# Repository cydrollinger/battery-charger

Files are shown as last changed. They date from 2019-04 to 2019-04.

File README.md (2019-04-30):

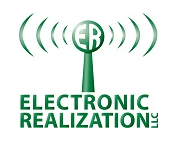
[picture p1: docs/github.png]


>Electronic Realization L.L.C.								   
>Design: Battery charger 4 Li cells		   
>Engineer: Cy Drollinger								   
>Date: 5/18												           
>Email: cy@elec-real.com	
>Website: https://elec-real.com							   
>Address: 2023 Stadium Dr Suite 2B #210 Bozeman, MT 59715				   
>Phone: 406-539-8117	

**NOTE:**
 This design has been tested and functions as specified. The design is provided gratis, so, please 
 think critically while utilizing and or redesigning. Open electronic circuitry can be dangerous due 
 to easily shorting circuits which can generate immediate and intense heat resulting in fire. Conversation is
 welcome to improve this design and repository, but, be advised ER is a professional design house and
 monetary compensation is required for additional work toward this design enabling your success.			   
	 
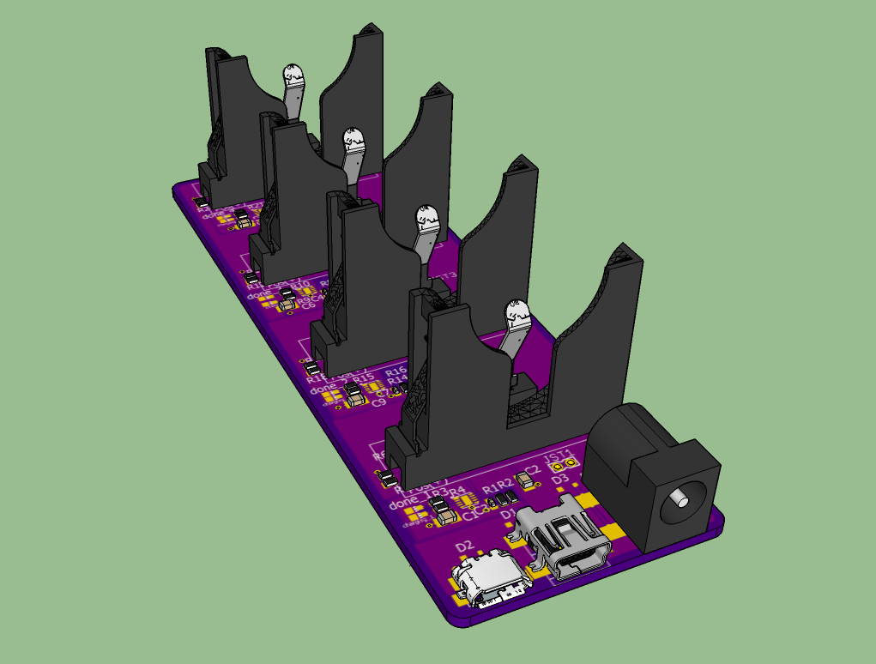
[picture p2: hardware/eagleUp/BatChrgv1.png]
Battery_charger


**PURPOSE:**
This is a hardware design that is capable of charging 4 Li ion cells. The design employs four different circuits
and charge currents: 100mA, 200mA, 400mA, and 800mA. The design files were created with Eagle Cadsoft v7.7 as a 
two layer board. Free Eagle version would be capable of viewing, and editing these files for redesign. 

>**File Arcitecture with a terse description**

* FOLDERS:
	* docs		: datasheets charging IC and battery holder
	* hardware	: eagle cadsoft(v7.7) hardware design files 	
		* eagleup		: 3D files 
		* library		: eagle part files 
		* manufacturing	: files required to produce the design
			* bom	: files created to order the parts
					* batteryCharger.txt	: 
					* batteryv1.1.csv	: digikey order
					* hundredUnits.txt	
			* gerber	: files generated to manufacture the board
			* 
	* readme.md	: this file

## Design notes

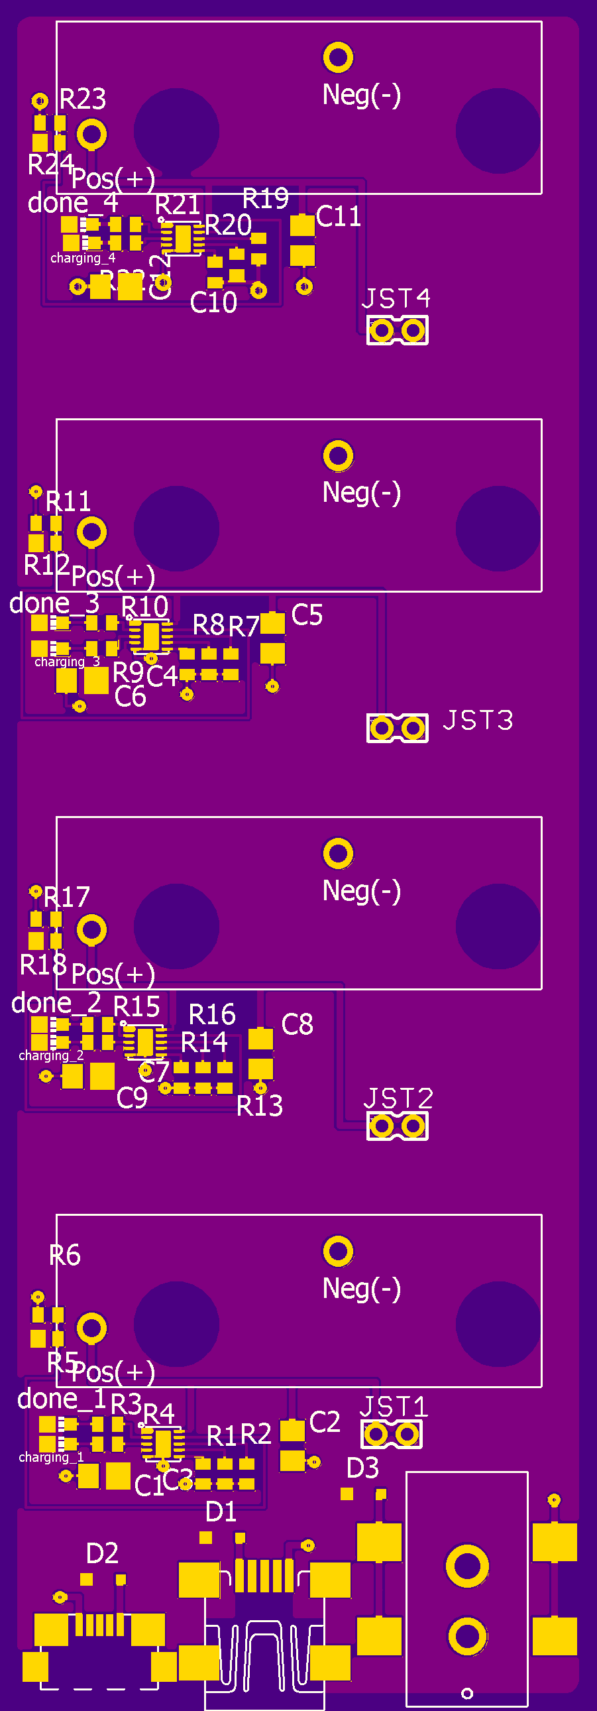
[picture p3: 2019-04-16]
hardware/eagleUp/eagleUp_batteryCharger_board_top.png

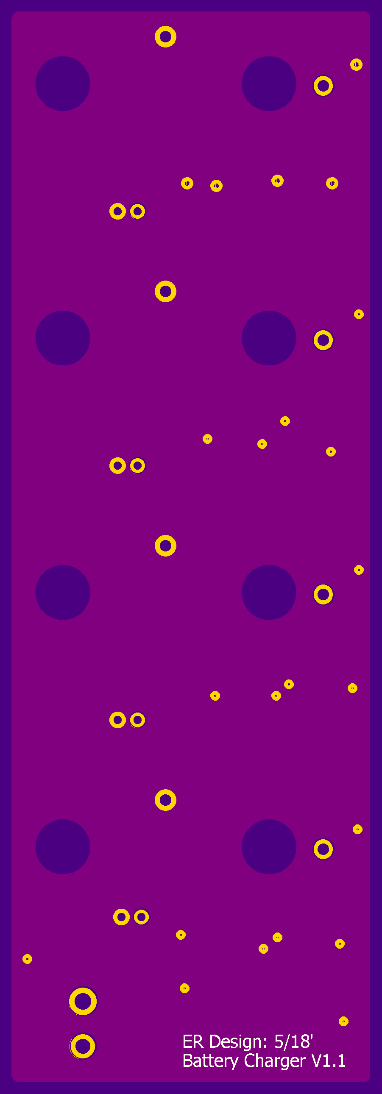
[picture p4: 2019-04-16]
hardware/eagleUp/eagleUp_batteryCharger_board_bottom.png

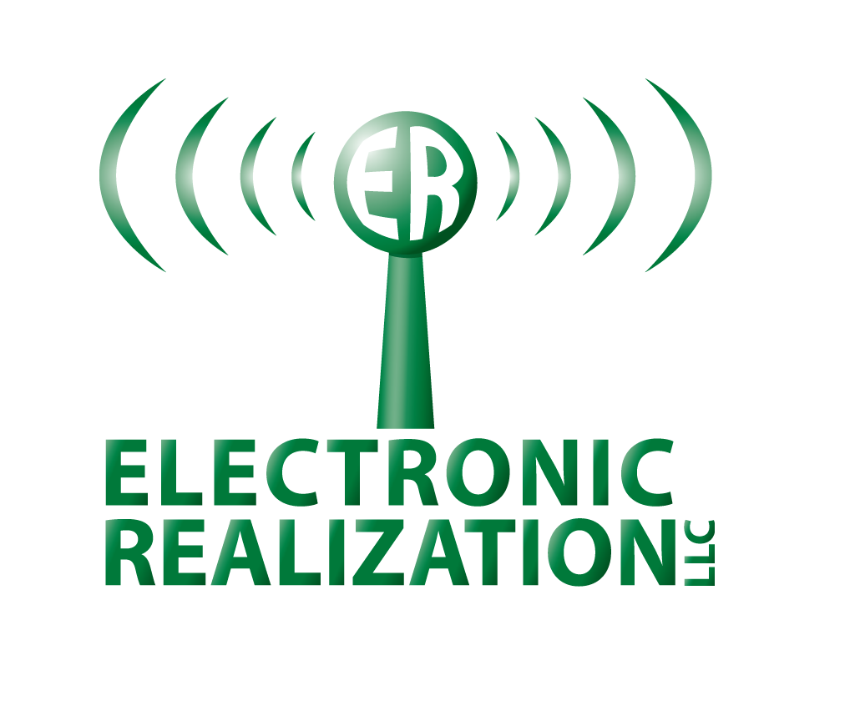
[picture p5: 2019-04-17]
docs/gihu.png

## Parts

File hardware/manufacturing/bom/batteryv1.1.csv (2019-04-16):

Index | Quantity | Part Number | Description | Customer Reference | Available Quantity | Backorder Quantity | Unit Price USD | Extended Price USD
1 | 3 | CP-002AHPJCT-ND | CONN PWR JACK 2X5.5MM SOLDER |  | 3 | 0 | 1.44 | 4.32
2 | 12 | 36-1068-ND | HOLDER BATTERY COIN 24.5MM VERT | BATTERYCHARGER: HOLDER | 12 | 0 | 1.642 | 19.7
3 | 3 | H2961CT-ND | CONN RECEPT MINI USB2.0 5POS | BATTERYCHARGER: MINIUSB | 3 | 0 | 0.99 | 2.97
4 | 12 | 455-1704-ND | CONN HEADER PH TOP 2POS 2MM |  | 12 | 0 | 0.162 | 1.94
5 | 25 | 160-1446-1-ND | LED GREEN CLEAR 0603 SMD | BATTERYV1.1: LED1-8 | 25 | 0 | 0.1556 | 3.89
6 | 3 | 863-1512-1-ND | 1.6A LINEAR LI-ION CHGR 10TDFN | BATTERYV1.1 | 3 | 0 | 0.94 | 2.82
7 | 100 | RHM1.5KCECT-ND | RES SMD 1.5K OHM 5% 1/16W 0402 | BATTERYV1.1: R3,R4,R9,R15,R16,R21,R22 | 100 | 0 | 0.0057 | 0.57
8 | 10 | RHM16.5KCHCT-ND | RES SMD 16.5K OHM 1% 1/8W 0805 | BATTERYV1.1: R1 | 10 | 0 | 0.021 | 0.21
9 | 20 | RHM10KDCT-ND | RES SMD 10K OHM 5% 1/4W 0603 | BATTERYV1.1: R5,R12,R18,R24, | 20 | 0 | 0.087 | 1.74
10 | 10 | RHM8.06KCDCT-ND | RES SMD 8.06K OHM 1% 1/16W 0402 | BATTERYV1.1: R8 | 10 | 0 | 0.014 | 0.14
11 | 10 | P4.02KLCT-ND | RES SMD 4.02K OHM 1% 1/10W 0402 | BATTERYV1.1: R14 | 10 | 0 | 0.043 | 0.43
12 | 10 | YAG3048CT-ND | RES SMD 1.87K OHM 1% 1/16W 0402 | BATTERYV1.1: R20 | 10 | 0 | 0.013 | 0.13
13 | 10 | 445-2550-1-ND | SENSOR NTC 10K OHM 3380K 0402 | BATTERYV1.1: R6,R11,R17,R23 | 10 | 0 | 0.088 | 0.88
14 | 25 | 490-10693-1-ND | CAP CER 10UF 4V X5R 0402 |  | 25 | 0 | 0.18 | 4.5
15 | 20 | 490-6287-1-ND | CAP CER 0.1UF 6.3V X5R 0402 | BATTERYV1.1: C3,C4,C7.C10 | 20 | 0 | 0.035 | 0.7

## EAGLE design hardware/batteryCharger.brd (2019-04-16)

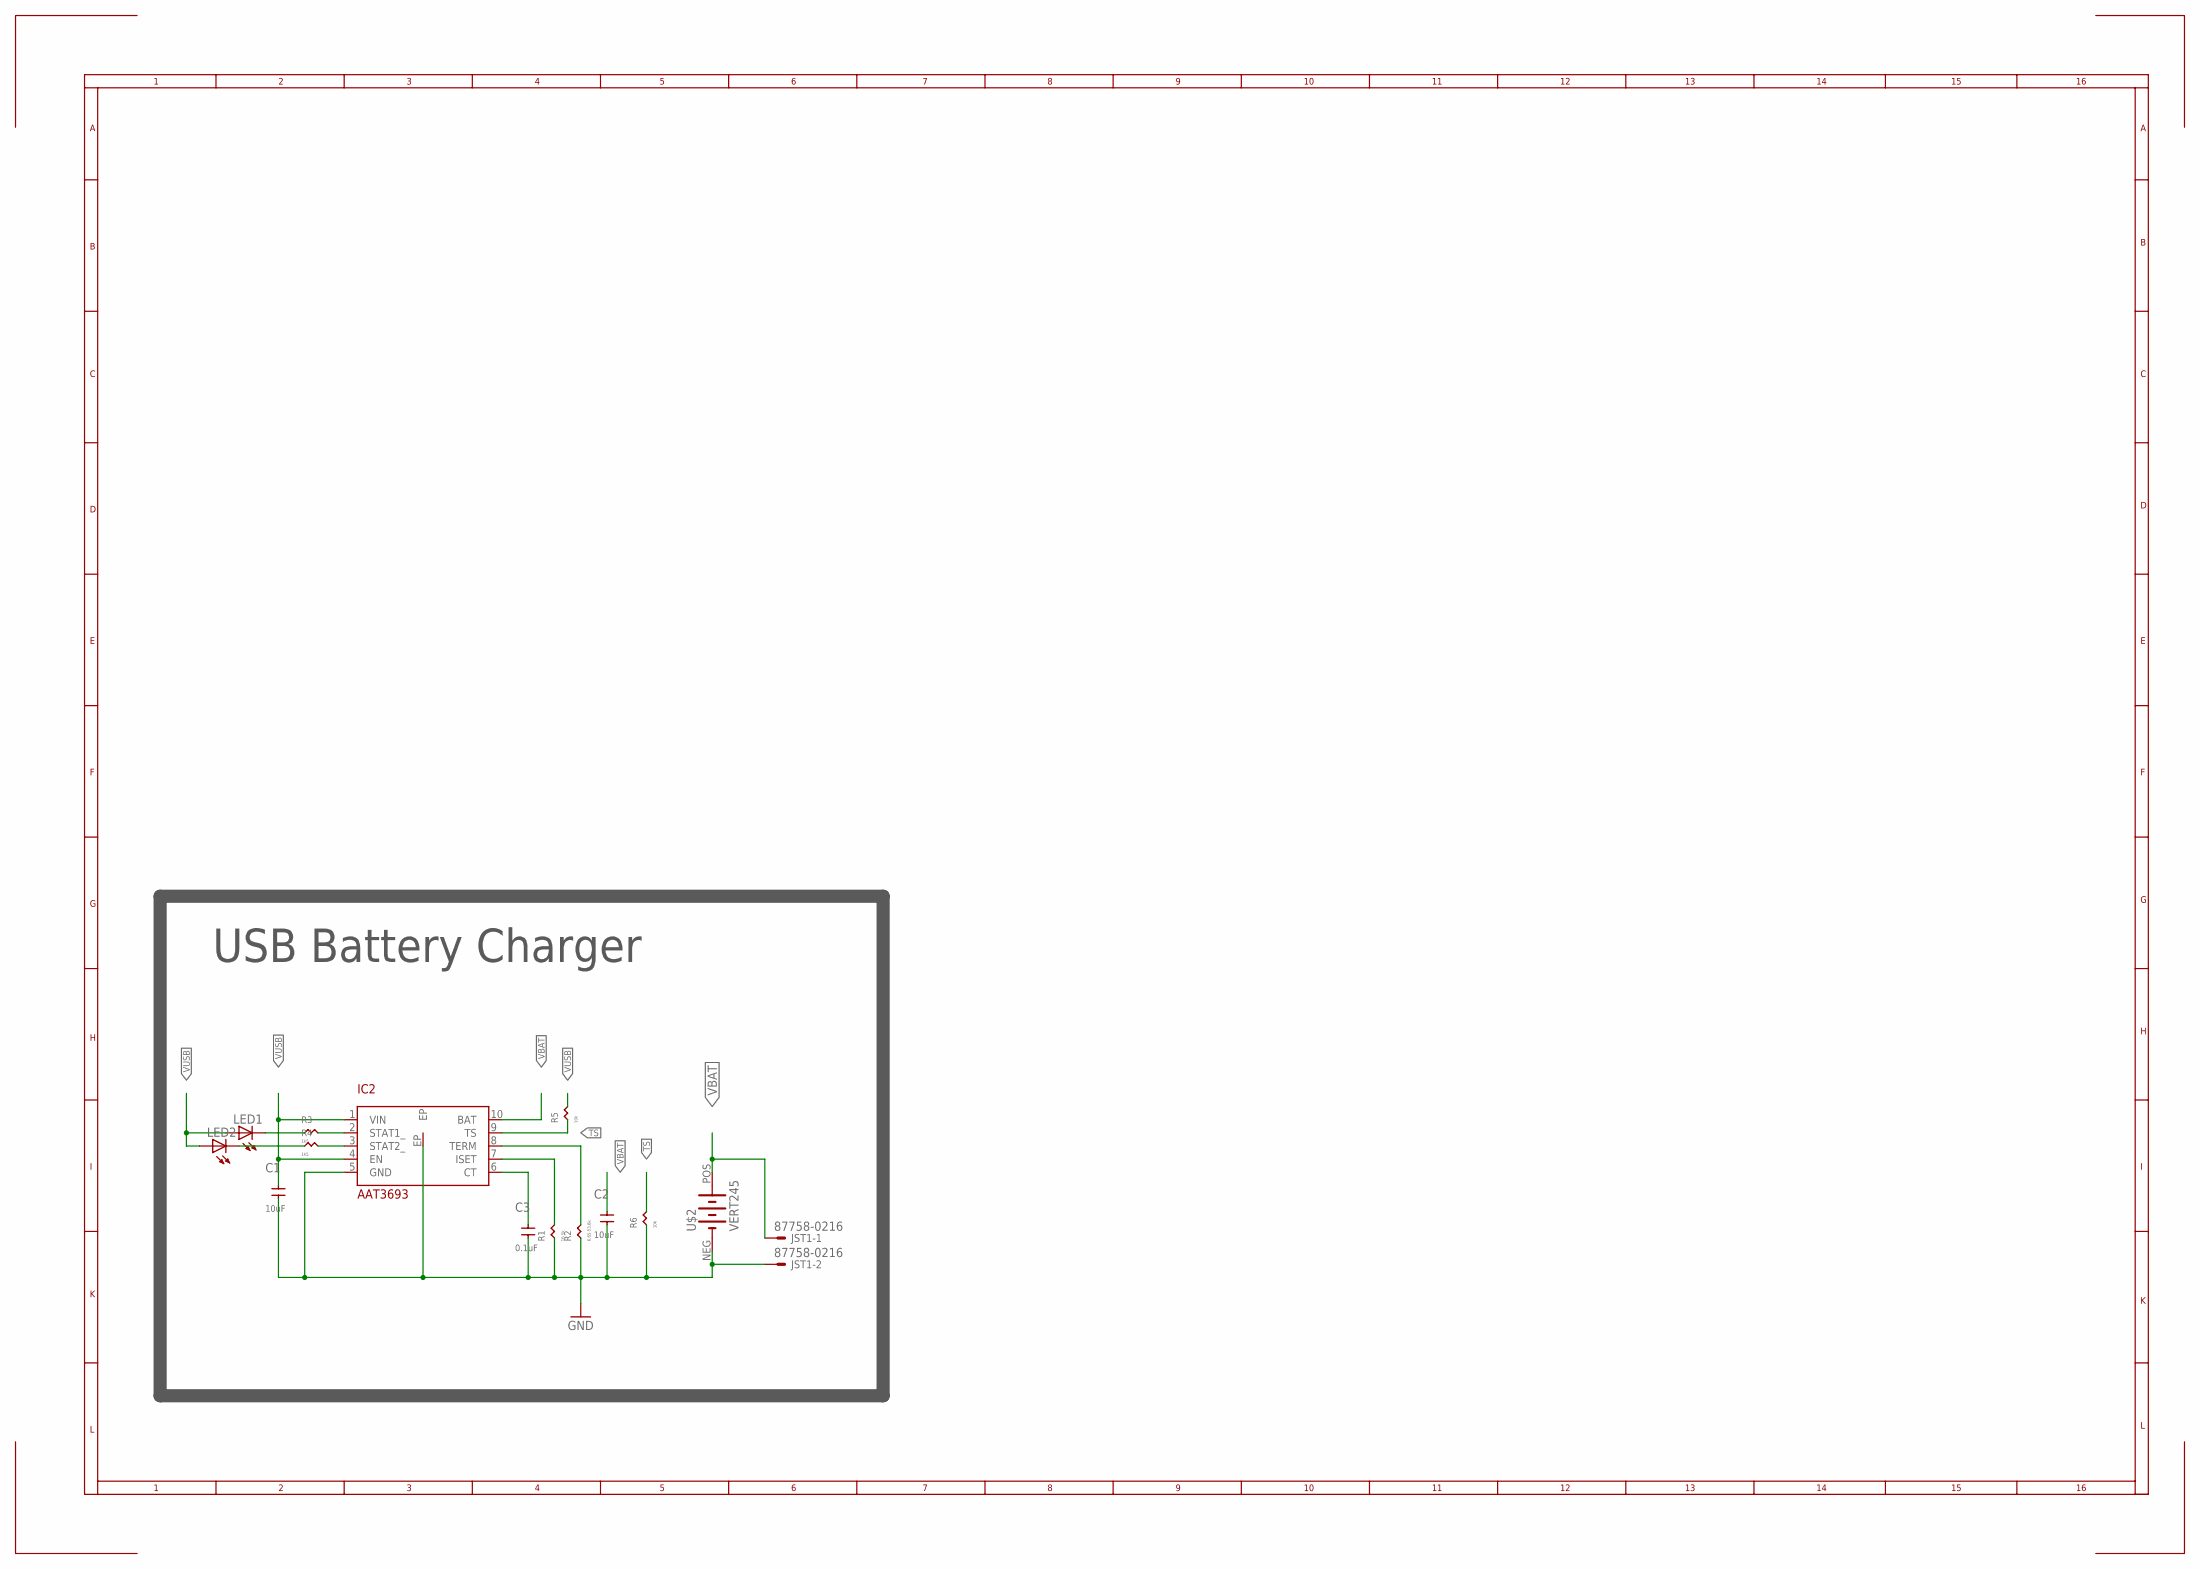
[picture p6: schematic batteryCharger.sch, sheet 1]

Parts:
C1, C2: 10uF; C0805
C3: 0.1uF; C0402
IC2: AAT3693
JST1: 87758-0216
LED1, LED2: LEDCHIP-LED0603; CHIP-LED0603
R1: 16.5k; R0402
R2: 6.65-53.6k; R0402
R3, R4: 1k5; R0402
R5, R6: 10k; R0402
U$2: VERT245

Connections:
GND: C1.1, C2.1, C3.1, IC2.5 (GND), IC2.EP, JST1.2, R1.1, R2.1, R6.1, U$2.NEG (-); also elsewhere on the board
unnamed: C3.2, IC2.6 (CT)
unnamed: IC2.7 (ISET), R1.2
unnamed: IC2.8 (TERM), R2.2
unnamed: IC2.3 (STAT2_), R4.2
unnamed: IC2.2 (STAT1_), R3.2
unnamed: LED1.C, R3.1
unnamed: LED2.C, R4.1
TS: IC2.9 (TS), R5.1, R6.2
VBAT: C2.2, IC2.10 (BAT), JST1.1, U$2.POS (+)
VUSB: C1.2, IC2.1 (VIN), IC2.4 (EN), LED1.A, LED2.A, R5.2; also elsewhere on the board

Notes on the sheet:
USB Battery Charger

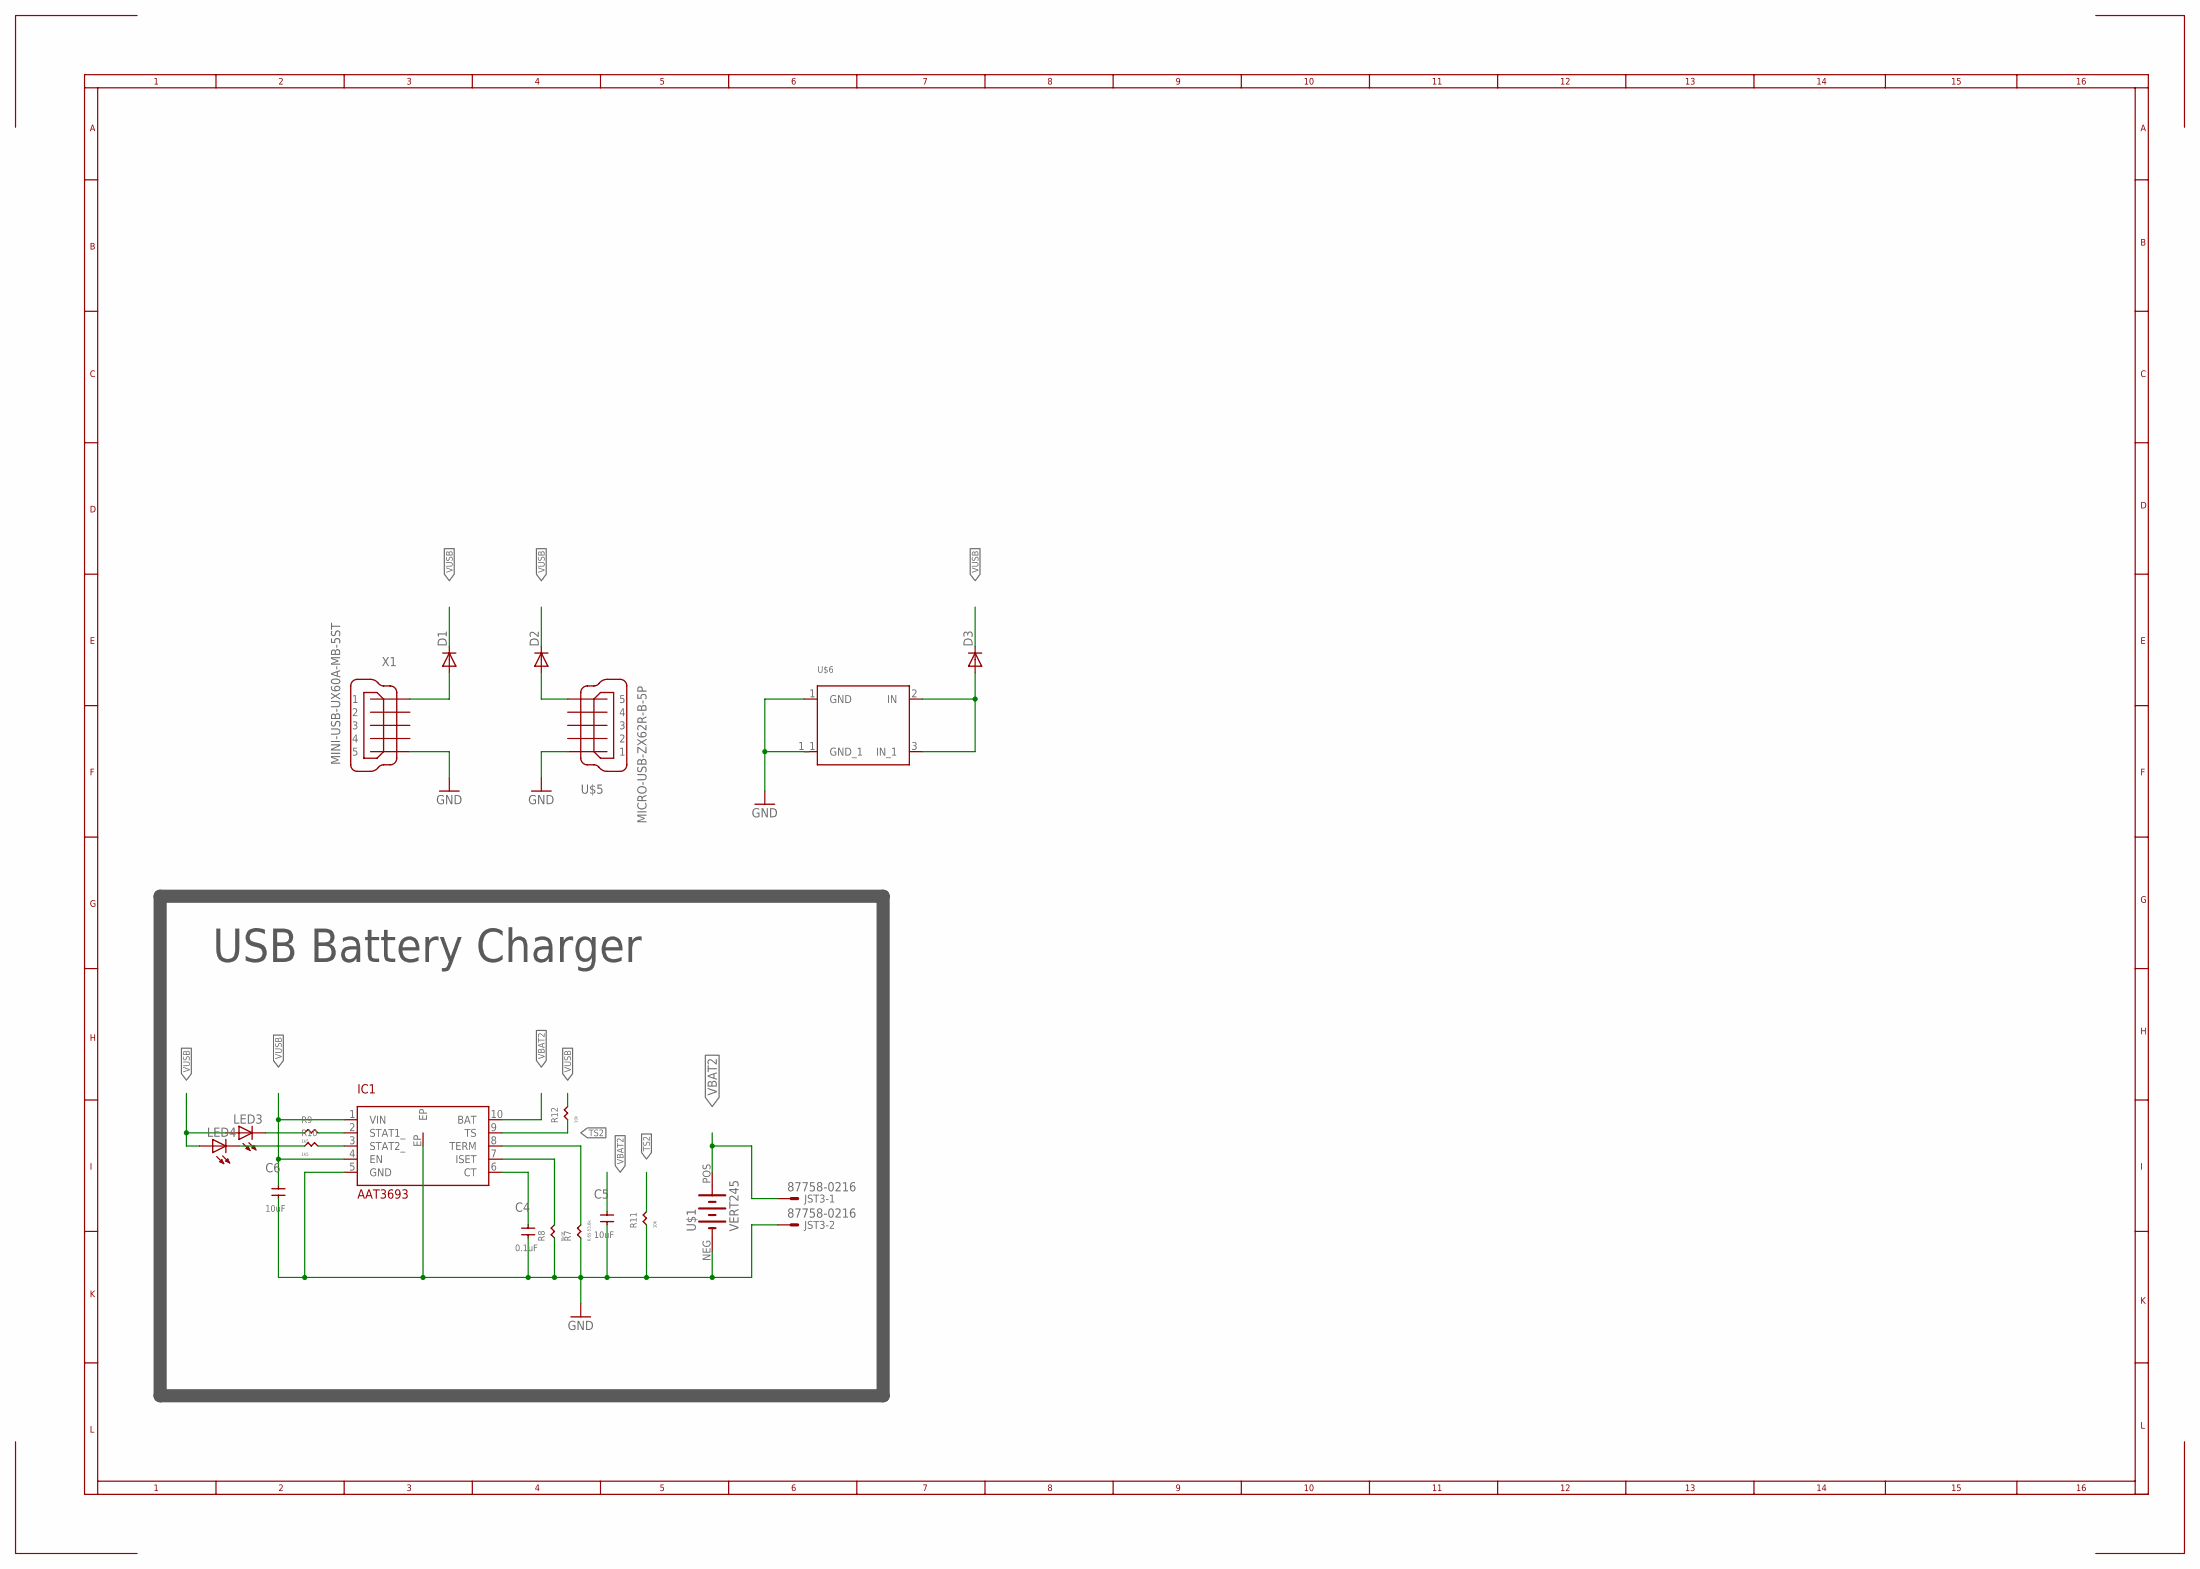
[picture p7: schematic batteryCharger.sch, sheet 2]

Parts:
C4: 0.1uF; C0402
C5, C6: 10uF; C0805
D1, D2, D3: DIODE-SOD323-R; SOD323-R; DIGIKEY BAT60AE6327HTSA1CT-ND
IC1: AAT3693
JST3: 87758-0216
LED3, LED4: LEDCHIP-LED0603; CHIP-LED0603
R7: 6.65-53.6k; R0402
R8: 8k06; R0402
R9, R10: 1k5; R0402
R11, R12: 10k; R0402
U$1: VERT245
U$5: MICRO-USB-ZX62R-B-5P; ZX62R-B-5P
U$6: PJ-002A_SMT
X1: MINI-USB-UX60A-MB-5ST; UX60A-MB-5ST

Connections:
GND: C4.1, C5.1, C6.1, IC1.5 (GND), IC1.EP, JST3.2, R7.1, R8.1, R11.1, U$1.NEG (-), U$5.1, U$6.1 (GND), U$6.1_1 (GND_1), X1.5; also elsewhere on the board
unnamed: C4.2, IC1.6 (CT)
unnamed: IC1.7 (ISET), R8.2
unnamed: IC1.8 (TERM), R7.2
unnamed: IC1.3 (STAT2_), R10.2
unnamed: IC1.2 (STAT1_), R9.2
unnamed: LED3.C, R9.1
unnamed: LED4.C, R10.1
unnamed: D1.A, X1.1
unnamed: D2.A, U$5.5
unnamed: D3.A, U$6.2 (IN), U$6.3 (IN_1)
TS2: IC1.9 (TS), R11.2, R12.1
VBAT2: C5.2, IC1.10 (BAT), JST3.1, U$1.POS (+)
VUSB: C6.2, D1.C, D2.C, D3.C, IC1.1 (VIN), IC1.4 (EN), LED3.A, LED4.A, R12.2; also elsewhere on the board

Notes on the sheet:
USB Battery Charger

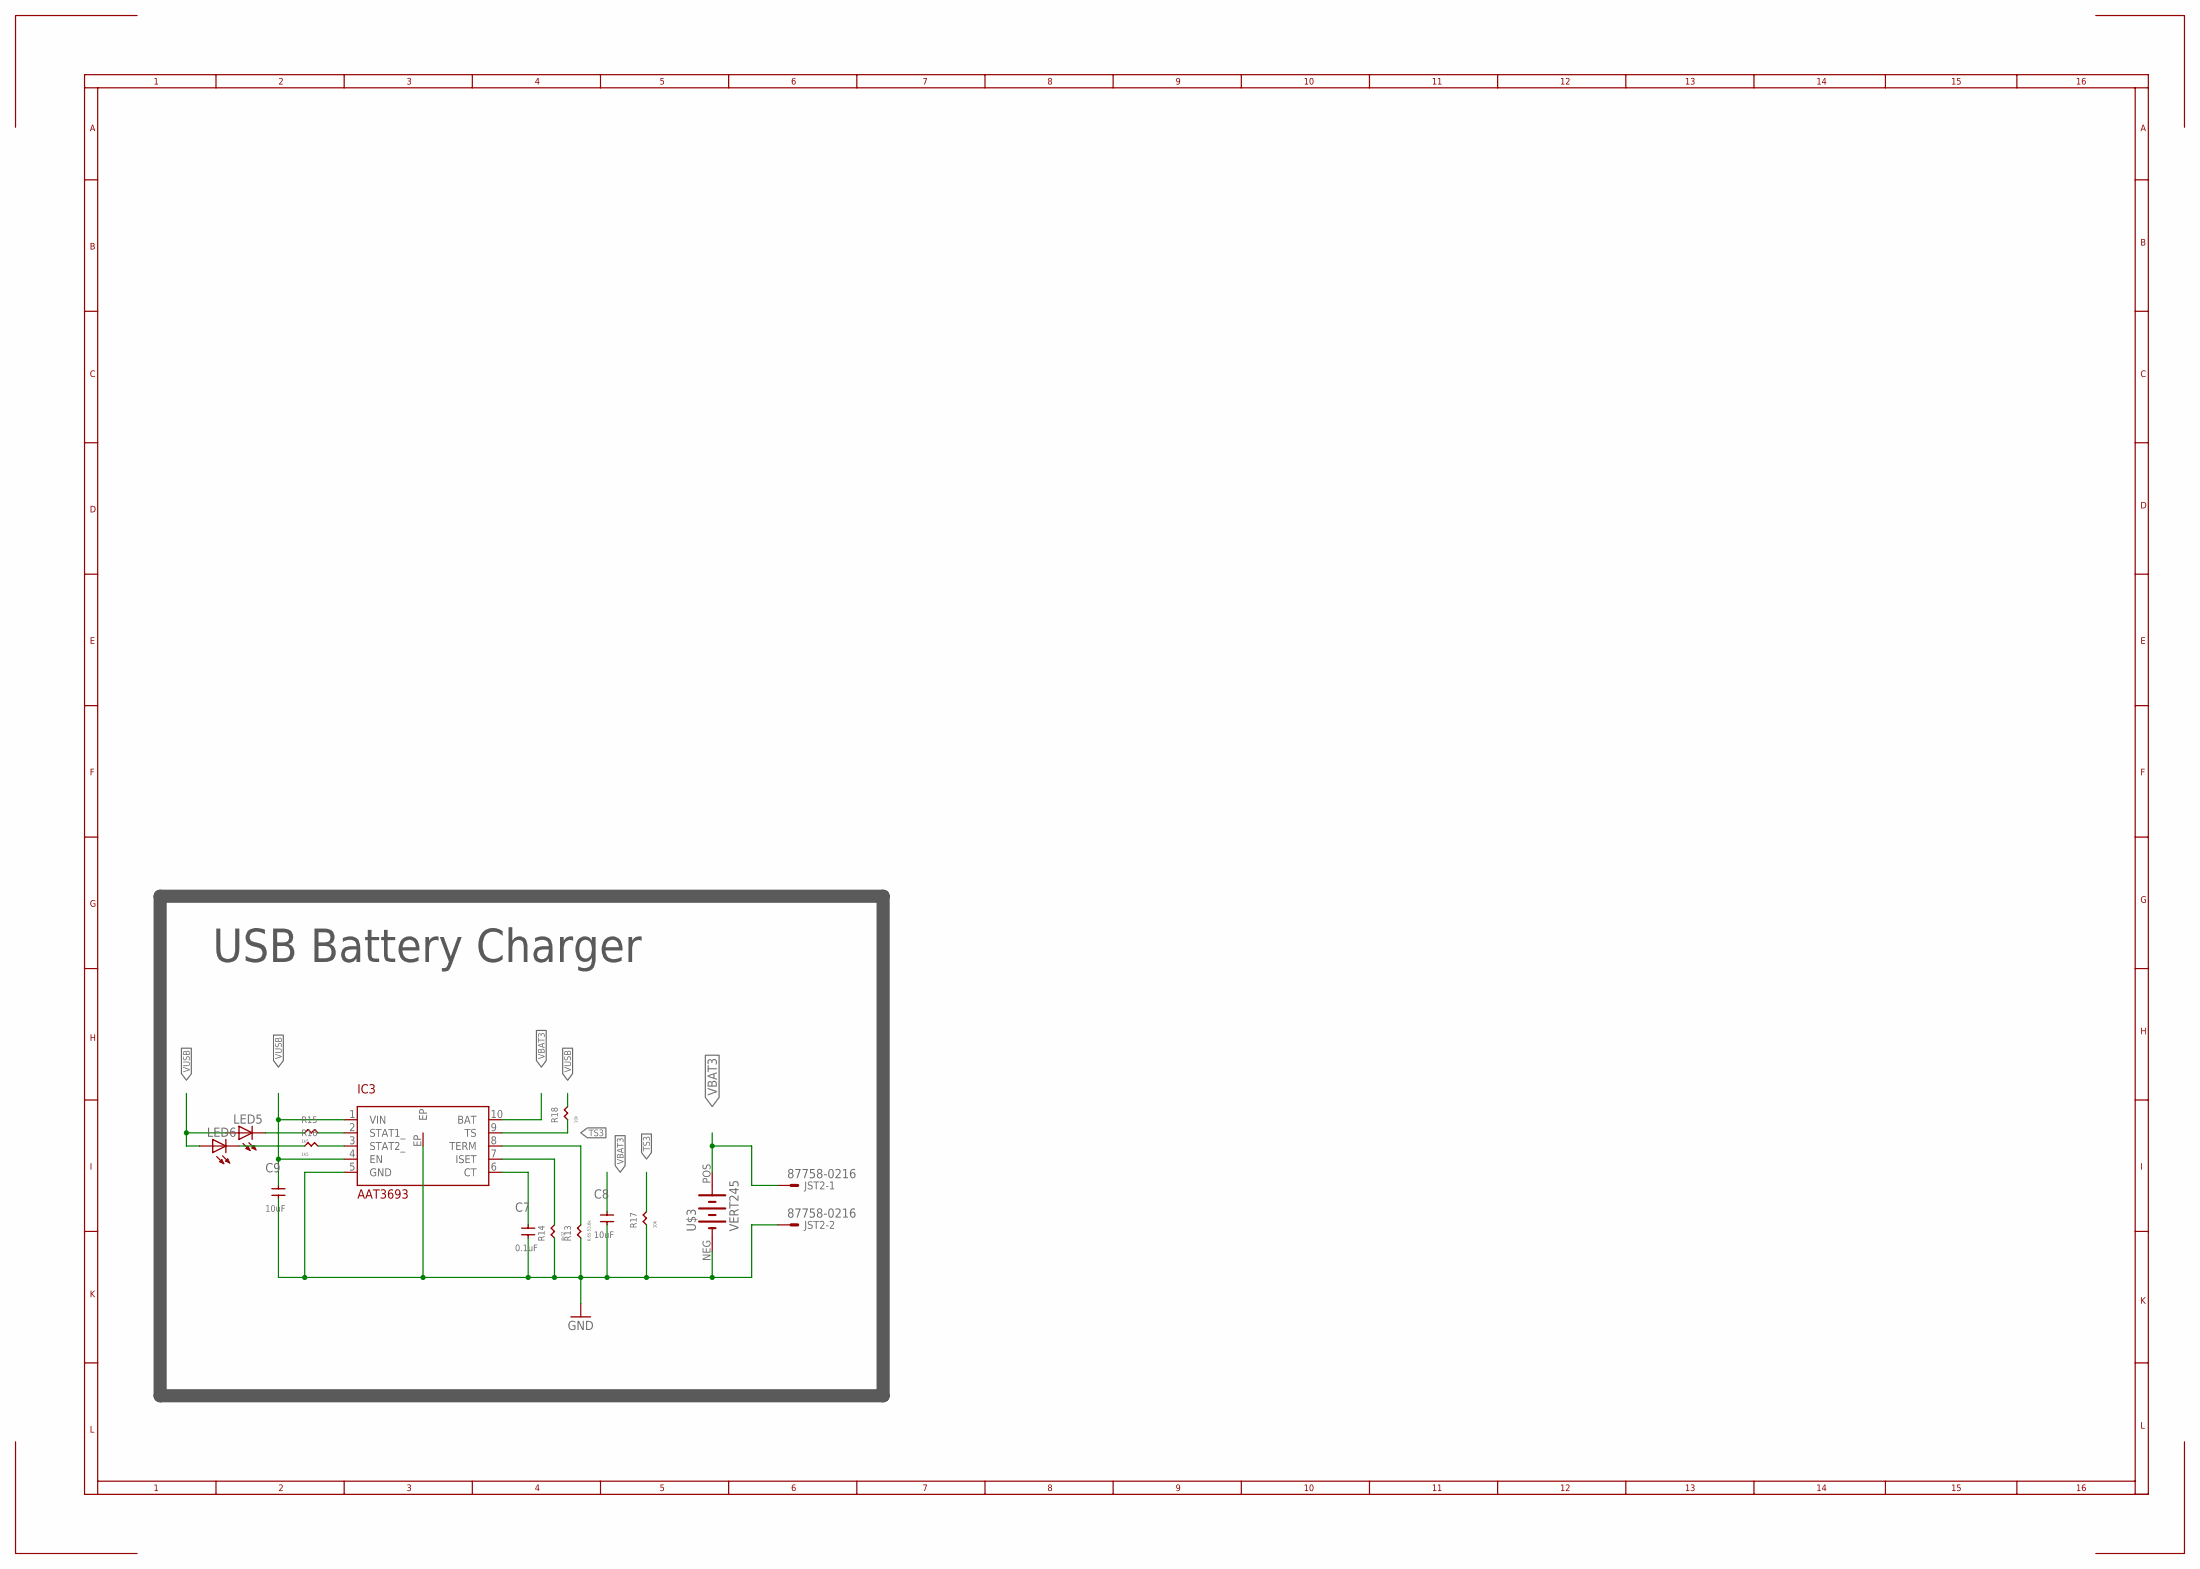
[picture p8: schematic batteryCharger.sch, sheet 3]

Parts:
C7: 0.1uF; C0402
C8, C9: 10uF; C0805
IC3: AAT3693
JST2: 87758-0216
LED5, LED6: LEDCHIP-LED0603; CHIP-LED0603
R13: 6.65-53.6k; R0402
R14: 4k02; R0402
R15, R16: 1k5; R0402
R17, R18: 10k; R0402
U$3: VERT245

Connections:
GND: C7.1, C8.1, C9.1, IC3.5 (GND), IC3.EP, JST2.2, R13.1, R14.1, R17.1, U$3.NEG (-); also elsewhere on the board
unnamed: C7.2, IC3.6 (CT)
unnamed: IC3.7 (ISET), R14.2
unnamed: IC3.8 (TERM), R13.2
unnamed: IC3.3 (STAT2_), R16.2
unnamed: IC3.2 (STAT1_), R15.2
unnamed: LED5.C, R15.1
unnamed: LED6.C, R16.1
TS3: IC3.9 (TS), R17.2, R18.1
VBAT3: C8.2, IC3.10 (BAT), JST2.1, U$3.POS (+)
VUSB: C9.2, IC3.1 (VIN), IC3.4 (EN), LED5.A, LED6.A, R18.2; also elsewhere on the board

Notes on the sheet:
USB Battery Charger

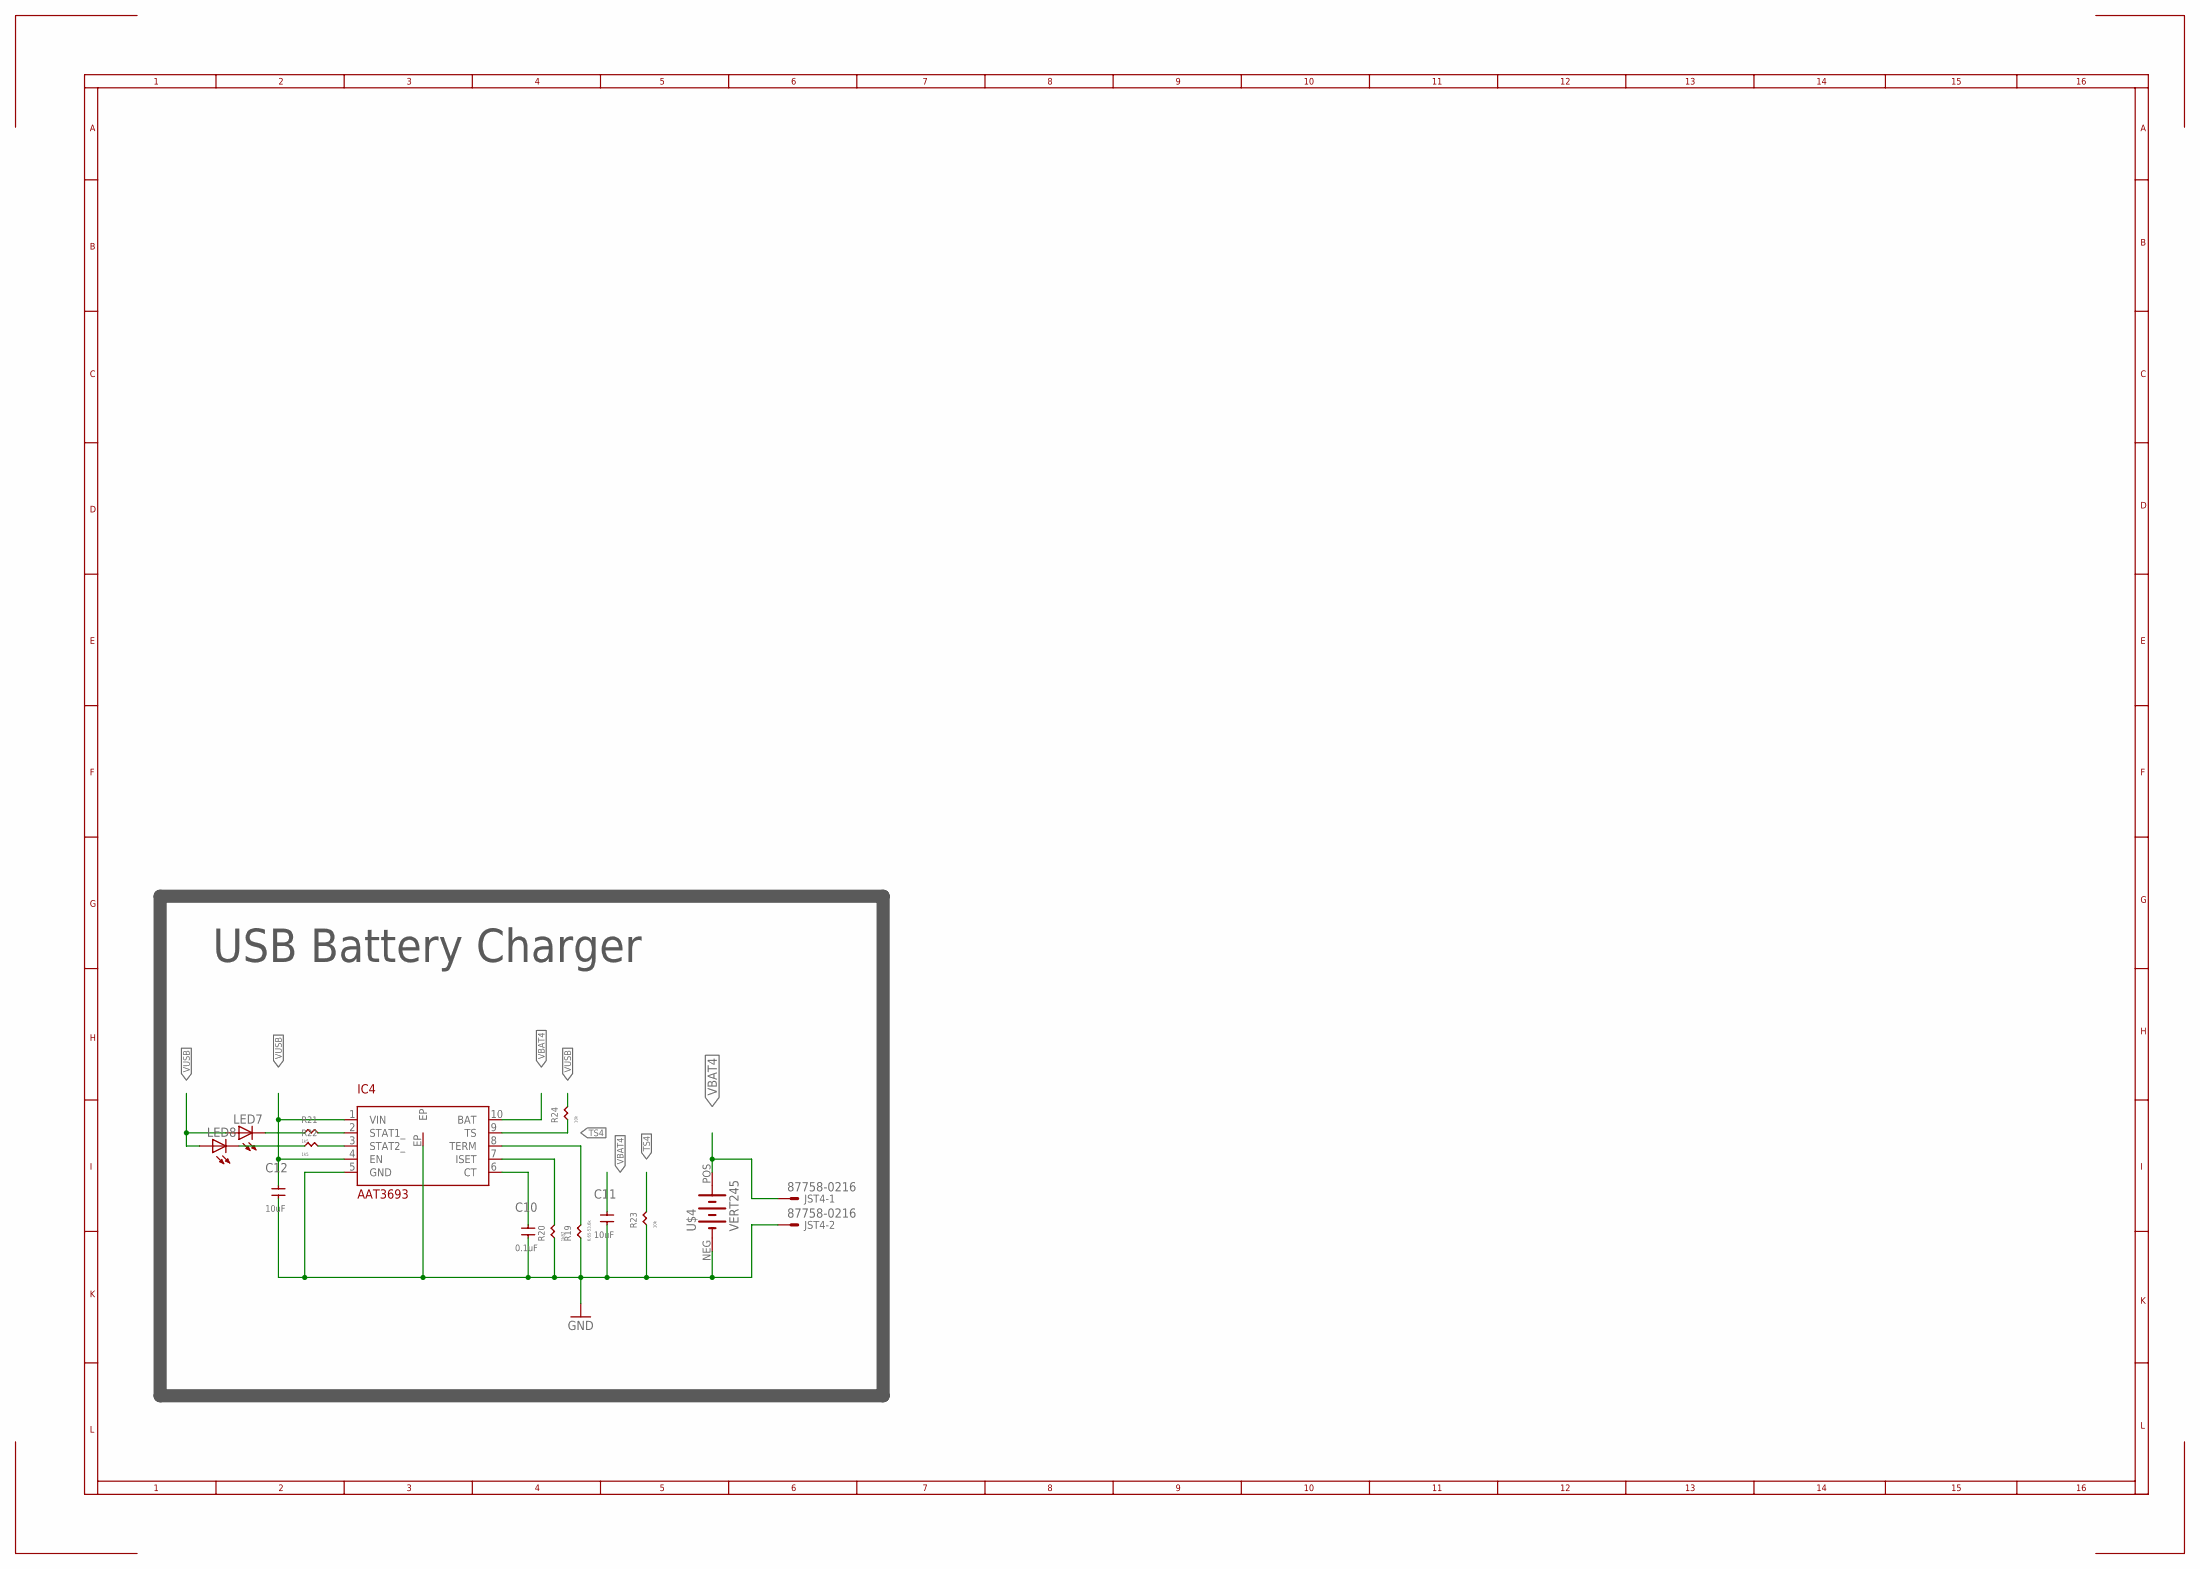
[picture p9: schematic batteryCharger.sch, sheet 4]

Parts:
C10: 0.1uF; C0402
C11, C12: 10uF; C0805
IC4: AAT3693
JST4: 87758-0216
LED7, LED8: LEDCHIP-LED0603; CHIP-LED0603
R19: 6.65-53.6k; R0402
R20: 1k87; R0402
R21, R22: 1k5; R0402
R23, R24: 10k; R0402
U$4: VERT245

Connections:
GND: C10.1, C11.1, C12.1, IC4.5 (GND), IC4.EP, JST4.2, R19.1, R20.1, R23.1, U$4.NEG (-); also elsewhere on the board
unnamed: C10.2, IC4.6 (CT)
unnamed: IC4.7 (ISET), R20.2
unnamed: IC4.8 (TERM), R19.2
unnamed: IC4.3 (STAT2_), R22.2
unnamed: IC4.2 (STAT1_), R21.2
unnamed: LED7.C, R21.1
unnamed: LED8.C, R22.1
TS4: IC4.9 (TS), R23.2, R24.1
VBAT4: C11.2, IC4.10 (BAT), JST4.1, U$4.POS (+)
VUSB: C12.2, IC4.1 (VIN), IC4.4 (EN), LED7.A, LED8.A, R24.2; also elsewhere on the board

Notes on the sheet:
USB Battery Charger

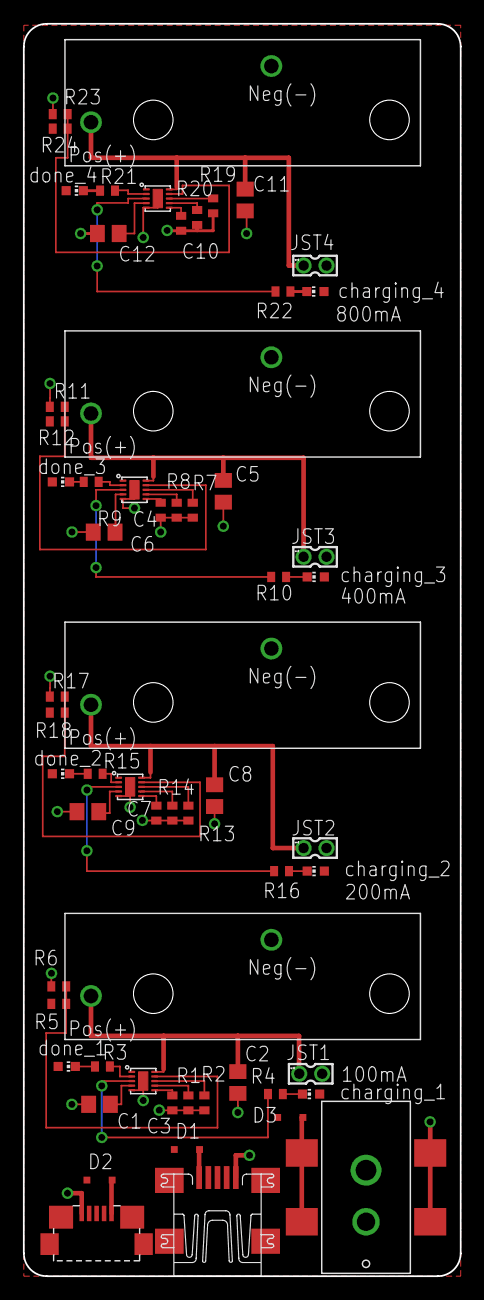
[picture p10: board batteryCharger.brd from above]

Board: 2 copper layers, 38.1 x 109.2 mm, 62 parts (0 on the bottom side), 41 nets.
